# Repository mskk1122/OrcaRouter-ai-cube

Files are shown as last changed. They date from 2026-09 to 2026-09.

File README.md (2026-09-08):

# AI Cube

머리를 톡 건드리면 이야기를 듣고 대답하는 작은 책상 친구. Raspberry Pi Zero2W와 OrcaRouter를 사용한다.

**이 저장소는 코드·배선·케이스를 포함한 제작용 프로토타입 패키지다. 실제 부품 조립 및 유료 API 호출은 아직 검증하지 않았다.**

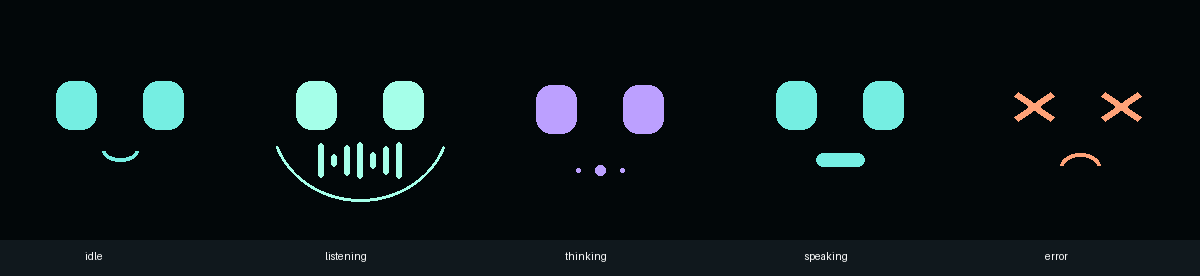
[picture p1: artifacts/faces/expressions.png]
상태별 화면


## 구성

- 약82×78×82mm 큐브, 둥근 모서리, 바깥에 센서가 드러나지 않는 머리.
- 1.3인치 컬러 화면: 대기 / 듣기 / 생각 / 말하기 / 오류 표정.
- 안쪽 정전식 전극과 AT42QT1010. 손을 대면 한 번 녹음하며 손을 떼어도 계속 듣는다.
- USB 마이크 → OrcaRouter 음성 이해·추론 → OrcaRouter TTS → MAX98357A와 스피커.
- 녹음 최대12초, 무발화5초 취소, 발화 후1초 무음 종료. 대기 중에는 마이크 입력을 열지 않는다.
- 유선5V 전원. 클라우드 추론이라 Pi에 대형 모델을 올릴 필요가 없다.

## 제작 파일

| 시작할 일 | 파일 |
|---|---|
| 부품 고르고 연결하기 | [BOM·정확한 배선](docs/hardware.md) |
| OS 설치부터 작동시키기 | [설치·점검·자동 실행](docs/setup.md) |
| 케이스 출력·조립하기 | [케이스 모델과 조립 안내](docs/enclosure.md), [CAD 폴더](cad/) |
| API 키·기기 설정 | [.env.example](.env.example) |
| 실행 코드 | [ai_cube](ai_cube/) |
| 부팅 자동 실행 | [systemd 서비스](deploy/ai-cube.service) |
| 검증 범위 확인 | [테스트 기록·실물 합격 기준](docs/verification.md) |
| 설계 기준 | [design.md](docs/design.md) |

```bash
python -m pip install Pillow numpy
python -m unittest discover -s tests -v
python -m ai_cube --simulate
```

위 명령은 PC에서 돌리는 오프라인 미리보기다. 실제 Pi 실행은 [설치 안내](docs/setup.md)를 따른다. API 키는 기기의 `.env`에만 넣는다.

## 동작

`머리 감지 → 듣는 표정 → 녹음 → 생각하는 표정 → API 답변 생성 → 말하는 표정과 음성 → 대기`

감지부는 플라스틱 안쪽의 **접촉·초근접 정전식 센서**다. 공중 감지 거리는 조립 상태에 따라 달라지므로 수cm 거리 감지를 보장하지 않는다. 음량 기반 발화 판정, 독립적인1회 질문, 상태 기반 입 애니메이션을 제공한다. 장기 기억·상시 청취·답변 도중 끼어들기는 구현 범위에 포함하지 않았다.

OrcaRouter의 [음성 입력 공식 문서](https://docs.orcarouter.ai/advanced/audio-input)와 [TTS 공식 문서](https://docs.orcarouter.ai/other-apis/tts)에 맞춘 어댑터다. 기본 음성 모델은 `google/gemini-2.5-flash`, TTS는 `openai/tts-1`. 모델 가용성·계정 권한·실제 응답은 본인의 키로 최종 확인해야 한다.

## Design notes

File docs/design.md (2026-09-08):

# AI Cube — 설계 기준 (2026-09-07)

사용자가 부품 선정·외형·구현을 위임한 새 프로젝트. 현재 작업 폴더는 파일과 커밋이 없는 초기 저장소이므로 이 폴더에 제작물을 만든다.

## 제품

- 책상용 둥근 모서리 큐브. 약 82 × 78 × 82 mm, 유선 5V 전원, 배터리 없음.
- Raspberry Pi Zero 2 W + Raspberry Pi OS Lite 64-bit, Python 3.11 이상.
- 전면 Waveshare 1.3inch LCD Module, ST7789 240×240 SPI: 검정 배경에 두 눈. 대기/듣기/추론/말하기/오류 표정.
- 머리 외부는 구멍이나 센서가 없는 불투명 비금속 플라스틱. 안쪽 35×35 mm 구리 전극, AT42QT1010 Adafruit #1374, 3.3V 동작. 접촉·초근접 감지를 목표로 하고 공중 감지 거리 보장 없음. 상판 센서 영역 1.0 mm, 그 외 2 mm. 센서 감지 후 손을 떼도 녹음 유지.
- Adafruit Mini USB Microphone #3367 + 짧은 Micro USB OTG 케이블. MAX98357A #3006 + 40 mm 4Ω 3W 스피커.
- USB 마이크는 입력, I2S는 출력 전용으로 나누어 GPIO 충돌 및 커스텀 전이중 오디오 드라이버를 피한다.

## 상태·개인정보

idle → listening → thinking → speaking → idle. 예외 시 error → idle.
대기 중 마이크 장치를 열지 않는다. 감지 후 최대 12초 녹음, 5초 무발화 취소, 발화 후 1초 무음 종료. 녹음 시작 전 스피커 알림음 사용 안 함. 듣기 중 화면으로 알린다.
한 번 감지당 한 대화만 실행. 처리 중 새 감지는 버리며, 대기 복귀 후 손을 떼고 다시 감지해야 재실행. 시작 시 손을 떼야 활성화. 키·음성·대화 본문은 로그에 쓰지 않고 오디오는 메모리/임시 디렉터리에서 처리 후 제거한다.

## API

공식 https://docs.orcarouter.ai/advanced/audio-input 과 /other-apis/tts 확인.
base URL https://api.orcarouter.ai/v1. POST /chat/completions에 WAV base64 input_audio를 보내 음성 이해+응답을 한 번에 요청. 기본 google/gemini-2.5-flash (공식 음성 입력 예시), 모델은 환경변수로 교체. 자동 라우터가 음성 지원 모델을 고른다고 가정하지 않는다.
POST /audio/speech, openai/tts-1, voice alloy, response_format wav. 동일 OrcaRouter 키 사용. 유한 timeout, HTTP 오류·잘못된 응답·오디오 오류 시 복귀. 클라이언트 자동 재시도 없음(중복 과금 방지). 실제 키가 없으므로 유료 API 성공 주장은 하지 않는다.

## GPIO 계약 (BCM)

LCD MOSI 10, SCLK 11, CS 8, DC 25, RST 27, BL 24.
AT42QT1010 OUT 17 (active high, 3.3V).
MAX98357A BCLK 18, LRC 19, DIN 21, VIN 5V, GND 공통.
스피커는 앰프 +/− 사이에만 연결한다.

## 산출물과 검증

Python 실행 코드, 오프라인 시뮬레이션, 오류·상태·무음·API 페이로드 테스트, systemd 예제, 한국어 설치/배선/BOM/제작 안내, 편집 가능한 CAD 및 STL, 실제 CAD 기반 미리보기.
실물 조립·GPIO·음성 품질·센서 거리·열·최종 끼움 공차는 미검증으로 명시한다. CAD 치수의 제조사 출처와 설계 여유/가정은 분리한다.

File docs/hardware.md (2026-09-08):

# 부품 선정과 배선

이 구성은 **Raspberry Pi Zero 2 W + USB 입력 + I2S 출력 + SPI 화면 + 디지털 정전식 센서**다. 모든 GPIO 번호는 BCM이며 물리 핀도 함께 적었다. 납땜과 조립은 전원을 분리한 상태에서 한다.

## 구매 목록

| 역할 | 선정 부품 / 수량 | 선정 이유·확인 사항 |
|---|---|---|
| 본체 | Raspberry Pi Zero 2 W ×1 | 65×30 mm, RAM512MB, 2.4GHz Wi-Fi. 연산은 API에서 수행 |
| 저장 | microSD 32GB, A1 등급 ×1 | Raspberry Pi OS Lite 64-bit. 카드·전원은 별도 |
| GPIO | 2×20 2.54mm 핀헤더 ×1 | Zero2W 기본형은 미실장. 직각/일자 선택 시 케이스 내부 높이 확인 |
| 얼굴 | Waveshare **1.3inch LCD Module, SKU15867** ×1 | ST7789, 240×240, PCB45×31mm. OLED/HAT/Pico 버전과 구분 |
| 마이크 | Adafruit **Mini USB Microphone #3367** ×1 | 약22.2×18.3×7mm. USB 오디오 입력, GPIO 미사용 |
| USB 케이블 | Micro USB 수 → USB-A 암 **OTG 데이터** 짧은 케이블 ×1 | Pi의 USB 포트에 연결. 커넥터와 꺾임 공간은 별도 필요 |
| 음성 앰프 | Adafruit **MAX98357A #3006** ×1 | I2S 입력, 모노 Class-D 출력. 5V 급전, 3.3V 신호 |
| 스피커 | Adafruit **#3968**, 40mm, 4Ω ×1 | 현재 제품명5W, 이전3W. MAX98357A 출력 범위로 구동. 약20mm 깊이 |
| 머리 센서 | Adafruit **AT42QT1010 #1374** ×1 | 순간형 active-high 출력. 토글형 AT42QT1012와 구분 |
| 숨김 전극 | 구리 테이프 35×35mm ×1 | 상판 내부에 붙이고 센서의 외부 전극 패드에 납땜 |
| 전원 | 정품급 **5.1V 2.5A Micro USB 전원** ×1 | Pi PWR IN 포트에 연결. 배터리/충전 회로는 사용하지 않음 |
| 배선 | 짧은 절연선, 수축튜브, 소형 전원 분배 기판 | 납땜 또는 고정 커넥터. 뒤틀리는 임시 점퍼는 최종 조립에서 고정 |
| 제작 부자재 | PLA/PETG, 나일론 나사·너트, 얇은 절연 테이프, 폼 가스켓, 케이블타이 | 규격·수량은 [케이스 안내](enclosure.md) 기준 |

가격은 지역·배송·보드 리비전에 따라 달라지므로 구매 시 위 **제품 번호**를 기준으로 확인한다. 실제 부품 구매는 수행하지 않았다.

## 전원과 신호

| 부품 단자 | Raspberry Pi BCM / 전원 | 물리 핀 | 비고 |
|---|---|---:|---|
| LCD VCC | 3V3 | 1 | 이 모델의 3.3V 입력 사용 |
| LCD GND | GND | 6 | 공통 접지 |
| LCD DIN | GPIO10 / MOSI | 19 | SPI0 |
| LCD CLK | GPIO11 / SCLK | 23 | SPI0 |
| LCD CS | GPIO8 / CE0 | 24 | SPI0.0, active-low |
| LCD DC | GPIO25 | 22 | 명령/데이터 |
| LCD RST | GPIO27 | 13 | active-low |
| LCD BL | **GPIO24** | **18** | 제조사 예제 GPIO18에서 변경! |
| QT1010 VIN | 3V3 | 17 | **5V로 구동하지 않는다**: OUT을 Pi에 직접 연결 |
| QT1010 GND | GND | 9 | 공통 접지 |
| QT1010 OUT | GPIO17 | 11 | 감지 시3.3V, 소프트웨어40ms 디바운스 |
| QT1010 외부 전극 패드 | 구리 전극 | — | 전원·GND가 아닌 외부 감지 패드. 짧은 절연선 |
| MAX98357A VIN | 5V | 2 | 앰프 전원은 GPIO 출력이 아닌5V 전원 핀 |
| MAX98357A GND | GND | 14 | Pi와 공통 |
| MAX98357A BCLK | GPIO18 / PCM_CLK | 12 | **LCD BL과 공유 금지** |
| MAX98357A LRC | GPIO19 / PCM_FS | 35 | I2S 워드 클록 |
| MAX98357A DIN | GPIO21 / PCM_DOUT | 40 | Pi에서 앰프로 출력 |
| MAX98357A SD/MODE | 연결 없음 | — | Adafruit 보드 기본 풀업/모노 믹스 사용. overlay의 no-sdmode와 짝 |
| MAX98357A GAIN | 연결 없음 | — | 기본 이득. 앱에서 PCM 볼륨25%로 시작 |
| 앰프 SPK+ / SPK− | 스피커 두 단자 | — | **스피커 어느 단자도 GND에 연결하지 않는다** |
| USB 마이크 | Pi **USB** → OTG → 마이크 | — | PWR IN 포트와 구분 |
| 전원 어댑터 | Pi **PWR IN** | — | 외부 전원 입력은 이 포트 하나 |

GPIO20(PCM_DIN) 및 SPI MISO는 이 설계에서 사용하지 않는다. GPIO와 전원핀은 서로 바꾸면 안 된다. 헤더 방향을 사진만 보고 추정하지 말고 보드의 1번 핀과 공식 핀맵을 확인한다.

```mermaid
flowchart LR
    PSU[5.1V / 2.5A 전원] -->|PWR IN| PI[Pi Zero 2 W]
    HEAD[상판 안쪽 구리 전극] --- CAP[AT42QT1010 · 3.3V]
    CAP -->|OUT · GPIO17| PI
    MIC[USB 마이크] -->|짧은 OTG · USB 포트| PI
    PI -->|SPI0 · BL GPIO24| LCD[ST7789 표정 화면]
    PI -->|GPIO18 / 19 / 21| AMP[MAX98357A · 5V]
    AMP -->|SPK+ / SPK−| SPK[4Ω 스피커]
    PI <-->|Wi-Fi · HTTPS| API[OrcaRouter · 음성 이해 / 추론 / TTS]
```

## 머리를 만지는 동작

센서는 상판 내부에 숨긴다. 상판 중심 감지 영역의 플라스틱 두께는1.0mm, 구리 전극은35×35mm다. **손을 가볍게 대거나 매우 가까이 가져가는 동작**을 목표로 한다. 이 부품은 거리 센서가 아니므로 수cm 떨어진 손을 안정적으로 검출한다고 보장하지 않는다. 기본 합격 기준은 케이스 외부 접촉으로 작동하는 것이며 비접촉 거리는 조립 후 기록한다.

전극은 매끈하게 밀착하고 도선은 가급적30mm 이내로 한다. 검정 도전성/탄소 섬유 필라멘트, 금속 도장, 전극 바로 아래 접지판을 피한다. 스피커 자석·앰프·클록선·전원선과 떨어뜨린다. 센서 보드의 표시 LED는 상판 밖으로 보이지 않도록 내부에서 차광한다. 플라스틱 소재, 습도, 케이블과 책상 접지 상태에 따라 감도는 달라진다.

완전히 조립한 뒤 손을 떼고 전원을 켜 자동 보정되게 한다. 짧은 접촉 후 손을 떼어 말하면 된다. 장시간 누르면 센서 자체의 보정/타임아웃 동작이 있을 수 있으므로 길게 누르는 제스처는 기능으로 쓰지 않는다. 감도가 부족하면 먼저 접착 공극·전극 연결·상판 두께를 확인한다. 감도 캐패시터 변경은 제조사 가이드와 데이터시트에 따른 실물 튜닝 단계이며, 코드 값으로 아날로그 감도를 높일 수는 없다.

## 소리·열·조립

- 마이크의 실제 음향 구멍을 케이스 마이크 그릴 쪽으로 향하게 하고 얇은 폼으로 통로를 만든다. 스피커와 마이크 사이에 폼을 넣어 기구 진동을 줄인다.
- 답변 재생 중에는 마이크 입력을 열지 않는다. 다만 말하는 중 끼어들기/에코 제거 기능은 제공하지 않는다.
- 스피커 선은 짧게 꼬아서 전극에서 떨어뜨린다. Pi 안테나 주변에는 구리 전극·금속·케이블 다발을 붙이지 않는다.
- 전원 분기에는 절연된 분배 기판을 사용하고 여러 선을 한 핀에 억지로 끼우지 않는다. 앰프 가까이100µF/10V 전해 캐패시터를 추가하는 것은 노이즈가 있을 때의 선택 부품이며 극성을 확인한다.
- 통풍구와 외부 전원 케이블을 막지 않는다. 조립 후30분 동작에서 온도와 저전압 플래그를 확인한다. 실물 발열·EMI·오디오 품질은 아직 시험하지 않았다.

## 제조사 근거 (2026-09-07 확인)

- [Raspberry Pi Zero2W 규격](https://www.raspberrypi.com/products/raspberry-pi-zero-2-w/)
- [Waveshare SKU15867 LCD](https://www.waveshare.com/product/displays/lcd-oled/lcd-oled-3/1.3inch-lcd-module.htm), [제조사 드라이버 예제](https://files.waveshare.com/upload/8/8d/LCD_Module_RPI_code.zip)
- [Mini USB microphone #3367](https://www.adafruit.com/product/3367)
- [AT42QT1010 #1374](https://www.adafruit.com/product/1374), [센서 가이드](https://learn.adafruit.com/adafruit-capacitive-touch-sensor-breakouts)
- [MAX98357A #3006](https://www.adafruit.com/product/3006), [Pi 설정 가이드](https://learn.adafruit.com/adafruit-max98357-i2s-class-d-mono-amp/raspberry-pi-usage)
- [스피커 #3968](https://www.adafruit.com/product/3968)
- [Pi Linux max98357a overlay 소스](https://github.com/raspberrypi/linux/blob/rpi-6.12.y/arch/arm/boot/dts/overlays/max98357a-overlay.dts): no-sdmode 옵션, 카드명MAX98357A 확인. 설치된 OS의 `dtoverlay -h max98357a`도 확인한다.

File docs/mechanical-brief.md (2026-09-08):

# Mechanical task — AI Cube

Own ONLY cad/ and docs/enclosure.md (plus docs/mechanical-report.md). Work in current empty project; no commits, no subagents. The parent builds code and hardware docs independently. User delegated all design choices, proceed without questions for reversible design work.

Design an attractive rounded compact desk cube roughly 82 W ×78 D ×82 H mm. You may increase slightly if engineering requires it, report decision early. Solid unmarked opaque top conceals 35×35mm copper capacitive electrode, top localized 1mm membrane, other walls ~2mm. Front Waveshare 1.3inch LCD Module ST7789 240×240, likely PCB40.5×37.5mm (verify official dimensions), active viewing roughly23.4mm square. Need correct accessible front window, retain LCD without adhesive on active display. Pi Zero2W board65×30mm holes58×23mm, M2.5 mounts; USB mic Adafruit3367 22.2×18.3×7mm excluding OTG cable/socket; QT1010 Adafruit1374 20×28mm; MAX98357A Adafruit3006 19.4×17.8mm allow 12mm height terminal/header; speaker40mm dia4ohm3W generic envelope depth20mm pending specific selection. Provide generic cable/service openings rather than pretend exact port cutouts verified. Power through Pi PWR IN; micro-USB OTG cable from Pi USB port to microphone. Plan enough cable connector+turn space (not just board boxes). Mic grille at front/side separated from speaker. Side/rear speaker grille, vents, removable screw-fastened base, reachable SD access via base acceptable. Nonmetallic fasteners/spacers or isolated mounting; top sensor board near electrode with short cable away from speaker/magnet and power lines. Top electrode not over grounded Pi.

Correction from official product search: Waveshare LCD PCB is 45.0×31.0mm, active23.4×23.4mm, PH2.0 connector. 40.5×37.5 is the OLED, not our LCD! Verify at https://www.waveshare.com/catalog/product/view/id/3637/s/1.3inch-lcd-module/category/356/ . Speaker pick Adafruit3968 (currently titled 4ohm5W, older3W), roughly square40mm driver. Verify envelope https://www.adafruit.com/product/3968 .

Deliver editable parametric CAD (OpenSCAD or reproducible Python CAD acceptable), actual binary/ASCII STL per printed part, actual mesh/CAD rendered PNG and preferably assembly/exploded preview. Need functional mounting/retention for all components including mic and amp (designed tie slots or removable brackets with tape support acceptable, document). State unverified purchased-board holes as measured-before-print parameters, do not fabricate dimensions. FDM PLA/PETG printable orientation, tolerances, screws+assembly Korean instructions. Verify STL closed/watertight, positive volume, separate print pieces, no detached islands intended as one part. Avoid unverified claim ready manufactured; label prototype CAD requiring physical dry fit. Can use bundled Python C:/Users/mskwo/.cache/codex-runtimes/codex-primary-runtime/dependencies/python/python.exe (Pillow+numpy available; no trimesh/manifold/cadquery initially). Can install CAD packages in .tools if needed without touching global Python. No openscad in PATH. Prefer real CSG via manifold3d if obtainable, else find installed CAD runtime read-only. Read official primary sources by web for dimensions. Use tools available. Final report docs/mechanical-report.md with commands, file names, key dimensions, issues. Parent will review. Keep response concise.

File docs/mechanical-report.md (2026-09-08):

# Mechanical delivery report — 2026-09-07

## Delivered

- `cad/enclosure.py`: editable parametric Python CAD with true Manifold Boolean solids; includes reproducible mesh export, geometric validation, and depth-buffer raster rendering.
- `cad/requirements.txt`, `cad/.gitignore`: pinned core CAD dependencies; locally installed `cad/vendor/` excluded from source control.
- `cad/stl/shell.stl`: 149,784-byte binary STL; print with exterior top on bed (already oriented).
- `cad/stl/base.stl`: 142,284-byte binary STL; print flat (already oriented).
- `cad/renders/assembly.png`, `exploded.png`, `cutaway.png`, `print-layout.png`: actual CAD mesh renders, 1280 × 1024 pixels; inspected visually. The cutaway and component blocks are reference illustrations, not extra printed parts.
- `cad/validation.json`: generated validation evidence.
- `docs/enclosure.md`: Korean sourcing notes, physical assembly, printing, fasteners, tolerances, routing, and limitations.

No commits, purchases, paid services, or changes outside the assigned CAD/doc ownership were made. CAD libraries required an approved network install and approved local DLL execution because the managed sandbox initially blocked them. Both succeeded; no approval blocker remains.

## Dimensions and design decisions

Kept 82 W × 78 D × 82 H mm. XY corner radius 6 mm, normal wall/top 2 mm, hidden local top membrane 1 mm over a 37 × 37 mm recess. Copper electrode is 35 × 35 mm. Unmarked top remains fully opaque and closed.

Official Waveshare primary product search and PDF confirm PCB **45 × 31 mm**, active **23.4 × 23.4 mm**, PH2.0 connector. Explicitly corrected the unrelated OLED 40.5 × 37.5 mm size. Front window is 25.4 mm square, display centre Z48 mm. LCD is retained at PCB edges by integral guides and nylon ties, without adhesive on the active display.

Adafruit3968 official page confirms 40 mm overall and 20 mm height; current title is 4 ohm 5 W, with a 2024 revision from the older 3 W design. A conservative 40 × 40 × 20 mm box fits the right-side U cradle. Frame foam and two ties behind the magnet retain it; the diaphragm is not clamped.

Pi is vertical at rear, on known 58 × 23 mm M2.5 centres, with PCB Z16–46. The grounded PCB plane lies outside the electrode footprint. USB edge faces upward, with connectors biased left. Reserved USB plug/turn corridor is 38 × 20 × 24 mm, and LCD lead corridor is 8 × 12 × 16 mm. Sensor is upper-left, mic lower-front-left, amp lower centre. Every component has a physical retention feature. Unknown board mounting-hole patterns are deliberately unused.

Base closes with four M3 nylon screws and captive nylon nuts. SD access requires base removal. Rear 20 × 9 mm opening is a generic service/cable opening with separate tie-down strain relief, not a falsely precise port cutout. Power goes to Pi PWR IN; microphone goes through a flexible OTG cable to Pi USB.

## Reproduction and actual checks

```powershell
& 'C:/Users/mskwo/.cache/codex-runtimes/codex-primary-runtime/dependencies/python/python.exe' -m pip install --target cad/vendor manifold3d trimesh
& 'C:/Users/mskwo/.cache/codex-runtimes/codex-primary-runtime/dependencies/python/python.exe' cad/enclosure.py
```

Final CAD command exited 0. It exports STL, reloads the files in trimesh, validates watertightness and winding, checks positive volume, and counts connected vertex components. It also evaluates actual Boolean intersections in assembly coordinates.

| Check | Shell | Base |
|---|---:|---:|
| Watertight | true | true |
| Consistent winding | true | true |
| Connected bodies | 1 | 1 |
| Volume mm³ | 66,473.29 | 26,121.65 |
| Triangles | 2,994 | 2,844 |
| Print bounds mm | 82 × 78 × 78.8 | 82 × 78 × 49 |

Shell/base intersection is numerical zero (5.33e−15 mm³). All seven reference component envelopes have zero intersection with printed material and one another. Both reserved cable corridors have zero intersection with printed material and reference component envelopes. These checks concern envelopes, not full supplier CAD models or routed cable simulations.

Visual verification opened all four PNGs. An initial painter-order preview artifact was corrected by implementing per-pixel depth buffering; final exterior correctly shows the unmarked solid top, LCD aperture, mic grille, side speaker grille, and removable base. No floating CAD islands were accepted.

## Remaining physical checks

This is prototype CAD requiring dry fit, not a manufacturing-qualified enclosure. Confirm display glass thickness and active-area centring, PCB-edge areas safe to clamp, PH2.0 direction, USB plug dimensions/turn radius, speaker revision/frame profile, foam thickness, and tie paths using purchased parts. Pi model is a board envelope rather than every mounted component. Confirm available clearance for headers and the actual microphone USB connection. Support generation, slicer review, fit coupons, tapping/reaming pilot holes, heat/acoustic/RF testing, and capacitive sensitivity calibration remain physical production steps. Internal ledges and the base frame require removable print supports.

Sources: [Waveshare LCD manual](https://files.waveshare.com/upload/7/70/1.3inch_LCD_Module_user_manual_en.pdf), [Waveshare product](https://www.waveshare.com/catalog/product/view/id/3637/s/1.3inch-lcd-module/category/356/), [Adafruit3968](https://www.adafruit.com/product/3968). The Waveshare direct open returned 403, but its official indexed product result and official PDF independently agreed on dimensions.

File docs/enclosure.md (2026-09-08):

# AI Cube 기구물 조립 안내

이 설계는 **실물 가조립이 필요한 FDM 시제품**이다. 외형은 82 × 78 × 82 mm, 모서리 평면 반경 6 mm, 일반 벽 두께 2 mm다. 상판은 불투명하고 표시·구멍 없이 막혀 있다. 안쪽의 37 × 37 mm 영역만 1 mm 두께로 줄여 35 × 35 mm 구리 전극을 숨긴다. 외피와 받침 사이의 설계 간격은 0.2 mm다.

## 파일과 재생성

- `cad/enclosure.py`: 편집 가능한 Python/Manifold CSG 원본. mm 단위이며 X 오른쪽, Y 뒤쪽, Z 위쪽이다.
- `cad/stl/shell.stl`, `cad/stl/base.stl`: 실제 이진 STL, 각각 **1개씩** 출력한다. 각 파일은 단일 연결 폐곡면이다.
- `cad/renders/assembly.png`: 실제 CAD 외관, `exploded.png`: 분해 참고도, `cutaway.png`: 전면 절개 부품 배치, `print-layout.png`: 출력 방향.
- `cad/validation.json`: STL 재로딩 검사와 부품·케이블 공간 간섭 검사 결과.

Python 3.12 환경에서 다음 명령으로 재생성한다. 설치는 프로젝트 로컬 폴더에만 한다.

```powershell
python -m pip install --target cad/vendor -r cad/requirements.txt
python cad/enclosure.py
```

주요 치수는 원본 상단에서 변경한다. 치수를 변경하면 고정 좌표로 정의한 배치도 함께 검토하고 검사를 다시 실행한다. `LCD_X`, `LCD_Z`는 실물 PCB 중심과 표시 영역 중심의 오프셋을 반영하는 값이다. `M25_PILOT`, `M3_CLEAR`, `M3_NUT_AF`는 프린터 보정용이다. 미확인 보드 장착 구멍은 사용하지 않았다. 좌우 뒤집힌 LCD나 Pi 방향은 소프트웨어 화면 회전 및 케이블 방향까지 확인한다.

## 부품과 공간

| 부품 | 설계 기준 / 배치 | 고정 방법 |
|---|---|---|
| Waveshare 1.3inch LCD Module | PCB 45 × 31 mm, 표시 23.4 mm 정사각형, 전면 창 25.4 mm, 중심 높이 48 mm | 전면 가장자리 받침과 양옆 가이드; 타이 2개를 슬롯에 통과시켜 **PCB 비활성 가장자리**만 눌러 고정 |
| Pi Zero 2 W | 65 × 30 mm, 홀 간격 58 × 23 mm, 뒤쪽 수직 배치; PCB 높이 Z16–46 | 받침 일체형 프레임 + 4개 M2.5 절연 나사, 스탠드오프 |
| Adafruit 3968 스피커 | 보수적인 40 × 40 × 20 mm 상자, 오른쪽 측면 | 40.8 mm 폭 U 받침, 얇은 폼 가스켓, 뒤쪽 슬롯에 타이 2개; 콘·진동판·단자에 힘을 가하지 않음 |
| USB 마이크 Adafruit 3367 | 22.2 × 18.3 × 7 mm, 아래 앞쪽 왼편 | 바닥 트레이 + 얇은 절연 패드 + 바닥 슬롯 타이; 수음 구멍을 가리지 않음 |
| MAX98357A Adafruit 3006 | 19.4 × 17.8 mm, 터미널 포함 12 mm 높이 공간 | 중앙 바닥 트레이 + 절연 패드 + 슬롯 타이 |
| QT1010 Adafruit 1374 | 20 × 28 mm, 위쪽 왼편 수직 배치 | 측벽 U 받침 + 절연 패드 + 슬롯 타이 |
| 구리 전극 | 35 × 35 mm, 상판 내부 앞쪽; X±17.5, Y−20.5…14.5 | 얇은 접착 구리박, 가장자리 절연; 센서와 짧게 연결 |

LCD 치수는 [Waveshare 공식 매뉴얼](https://files.waveshare.com/upload/7/70/1.3inch_LCD_Module_user_manual_en.pdf)과 [공식 제품 정보](https://www.waveshare.com/catalog/product/view/id/3637/s/1.3inch-lcd-module/category/356/)의 45 × 31 mm를 사용했다. 40.5 × 37.5 mm는 다른 OLED 제품 치수이므로 사용하지 않는다. 스피커는 [Adafruit 3968 공식 제품 정보](https://www.adafruit.com/product/3968)의 40 mm, 높이 20 mm를 적용했다. 현재 제품은 5 W로 표기되며 2024년 개정 이력이 있다. 나머지 보드 치수는 프로젝트 요구사항의 외곽 기준이며 수령품에서 확인한다.

Pi의 USB 단자 변이 위쪽이고 USB 단자들이 왼쪽에 오도록 놓는다. 상부 뒤쪽에 **38 × 20 × 24 mm** 커넥터·케이블 꺾임 공간(X−30…8, Y3…23, Z46…70)을 확보했다. 작은 유연한 OTG 연장선을 사용하고 단단한 USB 변환 젠더를 직접 꽂지 않는다. LCD PH2.0 리드는 왼쪽 여유 공간 **8 × 12 × 16 mm**로 배선한다. 커넥터의 실제 돌출, PH2.0 방향, USB 플러그 길이와 굽힘 반경은 반드시 실물 확인하며 이 공간 검사는 해당 케이블 호환성 인증이 아니다.

전원선은 후면 **20 × 9 mm 일반 서비스 개구부**로 넣어 Pi의 **PWR IN**에 연결한다. USB 마이크는 Pi의 **USB** 데이터 단자에 OTG 케이블로 연결한다. 후면 구멍에 모서리 보호용 그로밋을 끼우고 바닥 타이 슬롯으로 별도 장력 완화를 한다. 정확한 포트 일치 절개는 없다. SD 카드는 받침 나사 4개를 풀고 받침을 내려 접근한다. 마이크 선은 왼쪽, 스피커 전력선은 오른쪽으로 배선하고 센서 리드는 상판 왼쪽에 짧게 유지한다. Pi의 접지면은 Y22.4 이상으로, 전극 투영 영역과 겹치지 않는다.

## 출력 및 체결

PLA 또는 PETG, 0.4 mm 노즐, 0.2 mm 레이어, 벽 3줄 이상을 시작점으로 사용한다. 외피 STL은 이미 **상판이 출력 바닥에 닿도록 뒤집혀** 있다. 받침 STL은 바닥이 Z0에 놓여 있다. 상판 1 mm 막이 5개 레이어로 연속 출력되는지 슬라이서에서 확인한다. 윗면이 노출되는 디자인이므로 매끈한 빌드 플레이트를 권장한다.

내부 선반·너트 보스, LCD 창 상단, Pi 프레임 가로대와 수평 스탠드오프에는 **서포트가 필요하다**. 자동 서포트를 그대로 신뢰하지 말고 단면 미리보기에서 돌출 시작점을 확인한다. 트리/유기 서포트와 인터페이스를 사용하되 타이 구멍, 나사 구멍, 1 mm 막 안쪽은 과도한 접착을 피한다. 서포트 제거 후 모든 슬롯을 청소하고 가조립한다. 0.4 mm 좌우 여유 및 나사 구멍 공차는 프린터에 맞춰 조정한다. 상판 막을 사포로 더 얇게 만들지 않는다.

준비물: M3 나일론 나사 4개(약 12–14 mm, 실물 적층 높이로 최종 선택), M3 나일론 너트 4개, M2.5 나일론 나사 4개(약 6 mm), 절연 와셔, 폭 1.5 mm 이하 소형 나일론 타이 약 10개, 얇은 절연 패드, 스피커 프레임용 얇은 폼, 그로밋. 금속 체결재를 쓰면 보드 및 전극과 절연한다. 전극 주변에는 금속 체결재를 배치하지 않는다.

1. 수령한 보드·디스플레이·스피커와 USB/PH2 케이블의 실제 외곽과 돌출을 측정한다. LCD 표시 영역 중심, glass/PCB 두께와 커넥터 방향을 확인하고 필요하면 원본 매개변수와 가이드를 수정한다.
2. 출력물 서포트와 버를 제거한다. M2.5 파일럿은 적절한 탭으로 가공하거나 실물 나사에 맞게 조정한다. 억지로 조여 프레임을 쪼개지 않는다. 외피 보스 위쪽 육각 포켓에 M3 너트를 넣고 소량의 절연 테이프로 빠짐을 방지한다.
3. 외피 안쪽 상판에 전극을 붙이고 QT1010을 측벽 받침에 고정한다. 전극 배선을 짧게 연결하되 스피커 자석과 전원선에서 떨어뜨린다.
4. LCD를 전면 받침에 놓는다. 활성 유리면에는 접착제나 타이를 대지 않는다. 가이드 슬롯에 타이를 걸어 PCB 양끝의 안전한 가장자리만 지지한다. 부품이 그 자리를 차지하면 얇은 절연 스페이서를 추가하거나 가이드를 수정한다.
5. 스피커의 단단한 프레임에만 폼을 대고 U 받침에 넣는다. 측벽 슬롯을 연결하는 타이를 자석 뒤로 지나가게 해 프레임을 눌러 고정한다. 전기 단자와 진동판에는 닿지 않게 한다.
6. Pi를 받침 수직 프레임에 절연 나사로 체결하고, 마이크·앰프를 패드와 타이로 트레이에 고정한다. 마이크 수음부에서 전면 그릴까지 짧은 비밀폐 공기 경로를 확보한다. 필요하면 얇은 폼으로 안내하되 수음부를 막지 않는다.
7. 케이블을 연결하고 외피를 조심스럽게 씌워 선이 눌리지 않는지 확인한다. 아래에서 M3 나사 4개를 체결한다. 마지막 조임 전에 센서, 화면 정렬, 마이크 녹음, 스피커 재생, 전원 케이블 장력 완화를 확인한다.

최종 접촉 압력·낙하 강도·공진·마이크 피드백·RF·열 성능은 아직 실험하지 않았다. 통풍구는 후면에 있으나 연속 부하 온도 시험을 거쳐야 한다. 스피커와 마이크가 같은 작은 공간을 공유하므로 소프트웨어 재생/수음 정책과 실제 음향 시험도 필요하다.

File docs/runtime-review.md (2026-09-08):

# Runtime review — 2026-09-07

## Resolution — 2026-09-08

Both P2 findings below are resolved. Production requests run in a cancellable subprocess with a total timeout and bounded output; the slow loopback response regression passes. Display state transitions synchronously transfer a frame under an SPI lock before returning; failed listening transfer prevents capture. Error-screen/idle failures no longer replace the original interaction error. All 27 tests and the offline simulation pass. The findings below are retained as review history, not open defects.

Scope: `ai_cube/*.py`, `tests/*.py`, `pyproject.toml`, `.env.example`, `THIRD_PARTY.md`, against `docs/design.md`. This is a review of newly created files, not an existing commit diff. No runtime code was changed by this review.

## Actionable findings

### P2 — Enforce an elapsed deadline for API responses

Location: `ai_cube/provider.py:57-58`.

`self.open(..., timeout=self.timeout)` followed by one `response.read(limit + 1)` does not enforce a total request deadline. urllib documents the timeout as applying to blocking operations. A server or proxy that delivers occasional bytes inside each socket timeout can keep the cube in `thinking` far beyond `CUBE_API_TIMEOUT`; the large TTS size limit makes this particularly pronounced. The UI loop is blocked during the request and cannot accept a fresh interaction until it finishes.

Use a monotonic request deadline and bounded reads with each blocking wait constrained by the remaining time, or an isolated request worker with bounded cancellation and cleanup. Keep automatic retries disabled. Add a local slow-response test that sends bytes often enough to avoid the socket inactivity timeout but exceeds the total request budget. A plain fake response that returns immediately does not exercise this failure mode.

Reference: [Python urllib.request timeout documentation](https://docs.python.org/3/library/urllib.request.html#urllib.request.urlopen).

### P2 — Confirm the listening frame before opening the microphone

Location: `ai_cube/display.py:93-95`, used by `ai_cube/core.py` in `run_turn` immediately before `audio.record()`.

`show('listening')` checks the previous animation error and merely assigns `self.state`; the actual frame is sent by the background thread at its next update. Recording therefore begins while the LCD can still show idle. If that next SPI update fails, the microphone continues recording for the turn while the LCD remains idle, because the error is only checked after `record()` returns. The screen is the only recording indicator in the design.

Make state transitions acknowledge a successfully written frame before returning, with serialization of SPI operations. Abort before `arecord` is started if the listening frame cannot be written. Add a mocked display/SPI failure test verifying that a failed first listening frame prevents microphone capture. Consider checking display health during capture if a later animation failure must also stop recording.

## Confirmed by source inspection

- No microphone process is created at startup or idle; `arecord` is opened only in `record()` after a trigger.
- Release-to-arm behavior prevents a held touch at boot or the end of a turn from immediately triggering another turn; busy inputs are discarded by resetting the latch.
- Endpointer budgets are 12 seconds of PCM, 5 seconds without detected speech, and 1 second of trailing silence. A separate wall-clock watchdog bounds stalled capture to the configured duration plus 3 seconds, followed by process shutdown time.
- Capture and playback use `finally` cleanup; speaker WAV data is removed by a temporary-directory context on ordinary success, errors, or interruption. Abrupt power loss is outside this guarantee.
- HTTP bodies have explicit byte limits, redirects are disabled, response text is bounded, and audio format/duration/frame count are validated. Credentials and response contents are not written to application logs.
- The chat payload uses WAV base64 `input_audio`; TTS requests WAV from `/audio/speech`. These agree with the [official audio input example](https://docs.orcarouter.ai/advanced/audio-input) and [TTS documentation](https://docs.orcarouter.ai/other-apis/tts) inspected during this review.
- GPIO assignments in the runtime match the design contract, including backlight GPIO24 to avoid the I2S BCLK on GPIO18. Rendering uses small 240×240 buffers and NumPy conversion rather than a Python per-pixel loop.

## Verification limits

The parent agent reported 23 unit tests passing and `python -m ai_cube --simulate` passing. Those results are supplied evidence, not independently rerun in this review: `python` was not available on this review shell's PATH. Existing tests cover pure logic and payload construction, but not ALSA subprocess cleanup, LCD update synchronization, slow HTTP bodies, or physical hardware.

There is no real Pi, connected display/sensor/audio hardware, or API key available here. ST7789 orientation/offsets and actual SPI behavior, GPIO permissions, ALSA card names, MAX98357A channel behavior, sensor calibration, acoustic endpoint thresholds, and Zero 2 W CPU/thermal measurements remain hardware acceptance work. No real API success or physical integration success is claimed.

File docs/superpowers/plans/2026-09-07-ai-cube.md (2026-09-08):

# AI Cube Implementation Plan

> For agentic workers: use superpowers:subagent-driven-development for the independent mechanical task; keep runtime integration in the parent task. The user delegated design and implementation. No publication or purchase is requested.

**Goal:** Build a reviewable Pi Zero 2 W voice companion prototype package.
**Architecture:** GPIO trigger, bounded ALSA recording, OrcaRouter audio chat + TTS, SPI animated face. Independent parametric enclosure.
**Tech Stack:** Python 3.11+, standard-library unittest/urllib, Pillow, gpiozero, spidev, ALSA; parametric CAD.
**Spec:** ../../design.md

## Global Constraints

- Raspberry Pi Zero 2 W; Korean spoken responses; OrcaRouter for both inference and speech.
- No recording in idle. One interaction per fresh sensor activation. Busy touches never queue.
- GPIO mapping exactly as docs/design.md. No API keys or real audio included in source.
- Enclosure has a solid hidden capacitive top. Mesh validity does not imply physical fit verification.

## Task 1 — mechanical package

Files: cad/*, docs/enclosure.md. Detailed requirements: ../../mechanical-brief.md.
- [ ] Check component envelopes and manufacturers' dimensions.
- [ ] Model housing, removable base, mounts and access/ventilation openings.
- [ ] Export STL and rendered preview from the actual model; inspect solids and mounting fit numerically.
- [ ] Write assembly/printing instructions and measured-vs-assumed dimensions.

## Task 2 — runtime

Files: ai_cube/*.py, tests/*.py, pyproject.toml, .env.example.
- [ ] Write failing tests for silence termination, debounced release/retrigger behavior, API payload/invalid response and state transitions.
- [ ] Implement bounded PCM recording, provider client, expression renderer, hardware adapters, state loop.
- [ ] Run `python -m unittest discover -s tests -v`; run simulation with no hardware/key.

## Task 3 — integration and handoff

Files: README.md, docs/hardware.md, docs/setup.md, deploy/*, docs/verification.md.
- [ ] Document BOM, exact BCM+physical pins, power/OTG/speaker wiring.
- [ ] Provide explicit Raspberry Pi setup, audio device selection, sensor/display bring-up and service template.
- [ ] Review runtime/CAD together, correct defects, rerun affected checks.
- [ ] Deliver local file links with clear verified/unverified boundaries.

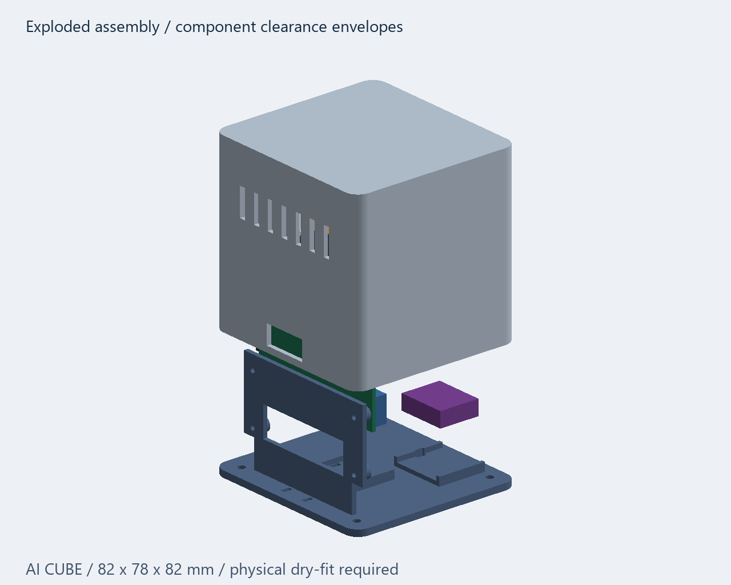
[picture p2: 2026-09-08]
cad/renders/exploded.png

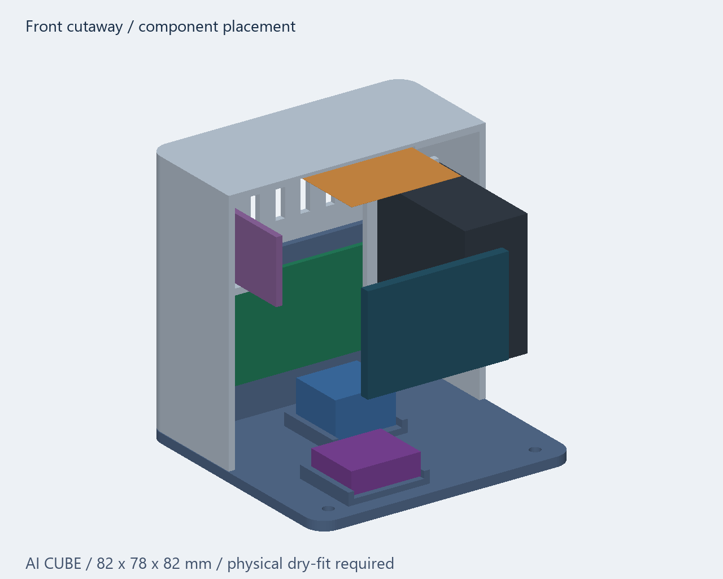
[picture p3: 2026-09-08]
cad/renders/cutaway.png

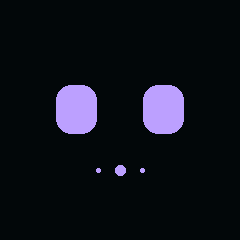
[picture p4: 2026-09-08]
artifacts/faces/thinking.png

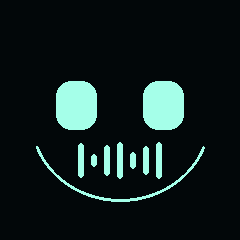
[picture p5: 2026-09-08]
artifacts/faces/listening.png

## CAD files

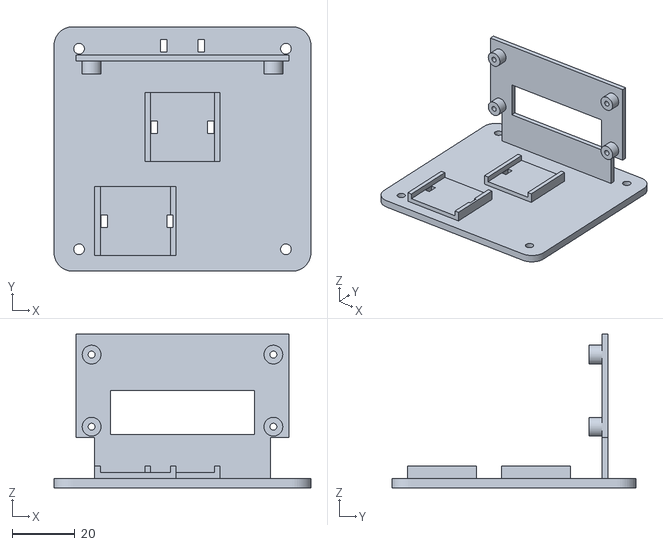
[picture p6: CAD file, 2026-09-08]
cad/stl/base.stl
82.0 x 78.0 x 49.0

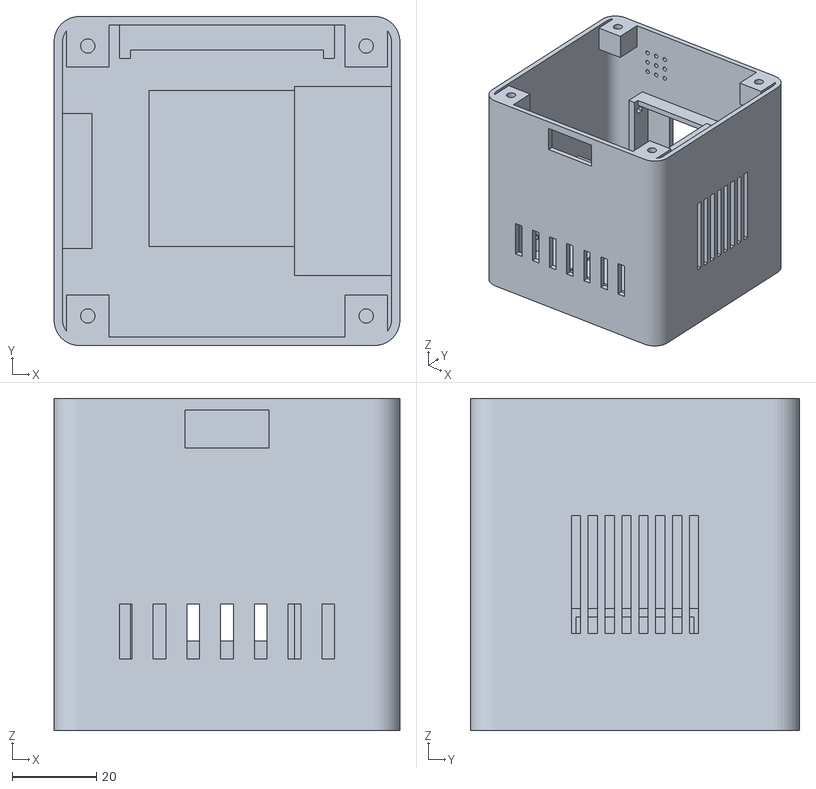
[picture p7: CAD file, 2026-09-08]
cad/stl/shell.stl
82.0 x 78.0 x 78.8

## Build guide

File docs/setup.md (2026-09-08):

# 라즈베리파이 설치·동작 점검

실물 없는 PC에서 검증된 부분과 Pi에서 직접 확인해야 하는 부분을 구분한다. 아래 명령은 **라즈베리파이의 터미널**에서 실행한다. PC 시뮬레이션은 맨 아래에 있다.

## 1. OS와 파일

Raspberry Pi Imager로 Zero2W에 Raspberry Pi OS Lite **64-bit**를 설치한다. Python3.11 이상이 있는 배포판을 사용한다. Imager에서 사용자 이름,2.4GHz Wi-Fi, SSH를 설정한다. 이 안내는 최신 부트 경로 `/boot/firmware/config.txt` 기준이다.

프로젝트 전체를 Pi의 `~/ai-cube`에 복사한다. `.tools`, `.git`, `__pycache__`는 복사할 필요가 없다.

```bash
sudo apt update
sudo apt install -y python3-venv python3-pip python3-setuptools python3-pil python3-numpy python3-gpiozero python3-lgpio python3-spidev alsa-utils rsync
cd ~/ai-cube
python3 -m venv --system-site-packages .venv
.venv/bin/python -m unittest discover -s tests -v
```

실행은 프로젝트 폴더에서 `python -m ai_cube`로 하므로 pip 패키지 설치는 필수가 아니다. 다른 경로에서 `ai-cube` 명령을 사용하려면 `.venv/bin/pip install --no-deps --no-build-isolation -e .`로 설치할 수 있다.

## 2. SPI와 스피커 overlay

먼저 [배선표](hardware.md)에 따라 연결한다. `/boot/firmware/config.txt`를 편집하고 기존 설정과 중복되지 않도록 `[all]` 아래에 다음을 넣는다. 기존 `dtparam=audio=on`은 주석 처리한다.

```ini
[all]
dtparam=spi=on
dtparam=audio=off
dtoverlay=max98357a,no-sdmode
```

`no-sdmode`는 이 프로젝트처럼 앰프의 SD 핀을 배선하지 않을 때 사용한다. 공식 Adafruit #3006의 기본 풀업을 전제로 한다. 다른 제조사의 MAX98357 보드는 SD 회로가 다를 수 있다.

```bash
dtoverlay -h max98357a
sudo usermod -aG audio,gpio,spi "$USER"
sudo reboot
```

재접속 후 확인한다.

```bash
ls /dev/spidev0.0
arecord -l
aplay -l
```

목록에 USB 마이크와 MAX98357A가 각각 있어야 한다. 카드 순번0/1은 부팅마다 달라질 수 있어 이름을 사용한다. 예를 들어 `card 1: Device [...]`라면 입력은 `plughw:CARD=Device,DEV=0`, `card 0: MAX98357A [...]`라면 출력은 `plughw:CARD=MAX98357A,DEV=0`이다. 실제 이름이 다르면 그대로 바꾼다. **예시 이름은 모든 USB 마이크에서 같지 않다.**

## 3. 설정

```bash
cd ~/ai-cube
cp .env.example .env
chmod 600 .env
nano .env
```

OrcaRouter 콘솔에서 발급받은 키를 `ORCAROUTER_API_KEY=`에 입력한다. 키는 채팅에 보내지 말고 기기에만 저장한다. 부품 테스트 전에는 비워두어도 된다.

| 값 | 기본값 | 의미 |
|---|---|---|
| ORCAROUTER_MODEL | google/gemini-2.5-flash | 공식 음성 입력 예시의 모델. 계정에서 사용 가능한 음성 지원 모델인지 확인 |
| ORCAROUTER_TTS_MODEL | openai/tts-1 | OrcaRouter의 `/audio/speech`로 호출 |
| ORCAROUTER_VOICE | alloy | TTS 목소리 |
| CUBE_CAPTURE_DEVICE | plughw:CARD=Device,DEV=0 | `arecord -l` 결과에 맞게 수정 |
| CUBE_PLAYBACK_DEVICE | plughw:CARD=MAX98357A,DEV=0 | `aplay -l` 결과에 맞게 수정 |
| CUBE_VOLUME | 0.25 | 0~1, PCM 볼륨 배율. 처음에는 낮게 유지 |
| CUBE_RMS_THRESHOLD | 550 | 1~20000, 음성 시작 판정의 PCM 에너지 기준. 정전식 감도와 무관 |
| CUBE_MAX_RECORD_SECONDS | 12 | 1~12초 녹음 상한 |
| CUBE_API_TIMEOUT | 45 | 각 API 요청의 전체 제한시간, 1~120초. 초과 시 요청 프로세스 종료 |
| CUBE_ROTATION | 0 | LCD 회전0/90/180/270 |

`.env`의 기존 운영체제 환경변수가 우선한다. 값은 단순 `KEY=VALUE` 형태이며 셸 명령·변수 치환은 실행하지 않는다.

## 4. 부품별 확인 — API 호출 없음

```bash
.venv/bin/python -m ai_cube --doctor
.venv/bin/python -m ai_cube --display-test
.venv/bin/python -m ai_cube --sensor-test
```

센서 테스트는 `detected` / `released`만 표시하고 녹음하지 않는다. 종료는 Ctrl+C. 화면 테스트는 대기/듣기/생각/말하기/오류를 차례로 표시한 뒤 꺼진다. 센서를 건드린 상태로 부팅하면 앱은 손을 떼기 전까지 대화를 시작하지 않는다.

아래 녹음 검사는 **명시적으로3초간 녹음**하므로 직접 말하며 실행한다. 장치명은 본인 기기에 맞게 바꾼다.

```bash
arecord -D plughw:CARD=Device,DEV=0 -f S16_LE -r 16000 -c 1 -d 3 /tmp/cube-mic-test.wav
```

앱과 같은25% 볼륨 변환·스테레오 변환을 적용해 스피커로 확인한다.

```bash
.venv/bin/python -c "from pathlib import Path; from ai_cube.__main__ import load_env; from ai_cube.config import Settings; from ai_cube.audio import AlsaAudio; load_env('.env'); AlsaAudio(Settings.from_env()).play(Path('/tmp/cube-mic-test.wav').read_bytes())"
rm /tmp/cube-mic-test.wav
```

화면 색상·방향·그림 잘림이 있으면 회전 설정과 **정확한 SKU15867** 여부를 먼저 확인한다. 다른 ST7789 모듈은 좌표 오프셋/초기화가 다를 수 있다.

## 5. 전체 동작

```bash
.venv/bin/python -m ai_cube
```

1. 머리에서 손을 떼고 기다린다. 대기 중에는 마이크 장치가 열리지 않는다.
2. 머리를 가볍게 건드린다. 민트색 듣기 표정이 되면 손을 떼고 말한다.
3. 약0.12초 이상 연속 소리가 나면 발화로 인식한다. 이후1초 무음이면 종료한다.5초 동안 말을 안 하면 취소하고, 계속 말해도12초에 종료한다.
4. 보라색 생각 표정에서 음성 이해·추론·TTS를 요청한다. 답변이 준비되면 입이 움직이며 재생한다.
5. 다시 머리에서 손을 뗀 상태를 거쳐야 다음 질문을 받는다. 처리 중의 접촉은 예약되지 않는다.

이 프로젝트의 무음 종료는 **간단한 음량 기반 판정**이다. 음악·팬 소음·긴 타격음도 발화로 오인할 수 있다. 조용한 환경에서 말소리가 잘리는 경우 기준을 조금 낮추고, 주변 소음으로 녹음이 끝나지 않으면 높인다. 화면의 듣기 막대와 말하기 입은 상태 애니메이션이며 실제 파형/입모양 동기화가 아니다.

현재 대화는 질문마다 독립적이다. 장기 기억과 이전 대화 전송은 없다. 녹음은 메모리에서 WAV로 만들어 OrcaRouter에 전송한다. TTS 음성은 재생용 임시 파일에만 두고 작업 종료 시 삭제한다. 강제 전원 차단까지 삭제를 보장하지는 않는다. 일반 로그에는 키·녹음·사용자 발언·답변 본문을 남기지 않는다. 인터넷 연결 및 OrcaRouter의 해당 모델 이용 권한·잔액이 필요하다.

## 6. 부팅 자동 실행 (부품 테스트 후)

서비스는 전용 계정과 `/opt/ai-cube`, `/etc/ai-cube.env`를 사용한다. 아래 계정 생성은 최초1회 실행한다. 이미 같은 이름의 계정이 있으면 재사용 여부를 먼저 확인한다.

```bash
sudo useradd --system --home-dir /opt/ai-cube --no-create-home --groups audio,gpio,spi ai-cube
sudo mkdir -p /opt/ai-cube
sudo rsync -a --exclude=.git --exclude=.env --exclude=.venv --exclude=.tools --exclude=__pycache__ ./ /opt/ai-cube/
sudo python3 -m venv --system-site-packages /opt/ai-cube/.venv
sudo install -m 600 -o ai-cube -g ai-cube .env /etc/ai-cube.env
sudo install -m 644 deploy/ai-cube.service /etc/systemd/system/ai-cube.service
sudo systemctl daemon-reload
sudo systemctl enable --now ai-cube
sudo systemctl status ai-cube
```

수동 실행 중인 앱은 Ctrl+C로 종료한 다음 서비스를 켠다. 두 프로세스가 GPIO와 오디오를 동시에 점유하면 안 된다.

```bash
journalctl -u ai-cube -n 50 --no-pager
sudo systemctl restart ai-cube
sudo systemctl stop ai-cube
```

서비스의 개인 임시 폴더는 tmpfs를 사용한다. 재부팅 시 임시 음성은 사라진다. 재생 중 전원을 바로 뽑지 말고 `sudo poweroff`로 종료한다.

## 문제 진단

| 증상 | 먼저 확인할 것 |
|---|---|
| LCD가 안 켜짐 | 3V3/GND, BL은GPIO24, SPI 활성화, gpio/spi 그룹, 단자 순서 |
| 감지 안 됨 | 센서VIN3.3V, OUT GPIO17, 외부 전극 패드 연결, 상판 공극·두께, 케이스 닫은 뒤 재보정 |
| 계속 감지됨 | 손을 떼고 재부팅, 전극과 접지/전원선 거리, 도전성 소재 여부 |
| 마이크 실패 | USB 포트와OTG 데이터 케이블, `arecord -l`, 카드 이름, 다른 녹음 프로그램 점유 |
| 소리가 안 남 | overlay 및재부팅, 앰프VIN5V, BCLK18/LRC19/DIN21, SPK 두 단자, 카드 이름 |
| 듣고 나서 오류 | 기기 시각/NTP, Wi-Fi, OrcaRouter 키·잔액·음성 모델 사용 권한, TTS 모델 |
| 소음이 질문으로 전송됨 | RMS 기준을 높이고 마이크 위치 조정. 현재 음량 게이트의 한계 |
| 재부팅/딱딱거림 | 전원 전압강하, 케이블, 볼륨, 앰프 전원 배선. 클록 시작/종료 팝은 실물에서 평가 |

```bash
vcgencmd measure_temp
vcgencmd get_throttled
```

조립 후30분 동작,50회 터치, 무발화10회, Wi-Fi 단절 후 복구를 시험한다. 자세한 합격 기준은 [검증 기록](verification.md)을 따른다.

## PC 오프라인 시뮬레이션

Python3.11 이상과 Pillow/numpy가 필요하다. Pi용 패키지는 설치하지 않아도 된다.

```bash
python -m pip install Pillow numpy
python -m unittest discover -s tests -v
python -m ai_cube --simulate
```

`artifacts/faces/`에 PNG/GIF를 만들고 상태 전이를 출력한다. 실제 API·녹음·스피커·GPIO를 사용하지 않는 시뮬레이션이다.

## API 근거

[OrcaRouter 음성 입력](https://docs.orcarouter.ai/advanced/audio-input)의 OpenAI형 `input_audio` 경로와 [TTS](https://docs.orcarouter.ai/other-apis/tts)의 `/audio/speech`를 사용한다. 음성 모델 선택을 보장할 수 없는 `orcarouter/auto`를 기본 입력 모델로 사용하지 않는다. 한 질문에 음성 포함 Chat 요청1회와 TTS 요청1회를 보내며, 클라이언트 자동 재시도는 하지 않는다. 서버의 과금 정책과 모델 목록은 콘솔에서 확인한다.

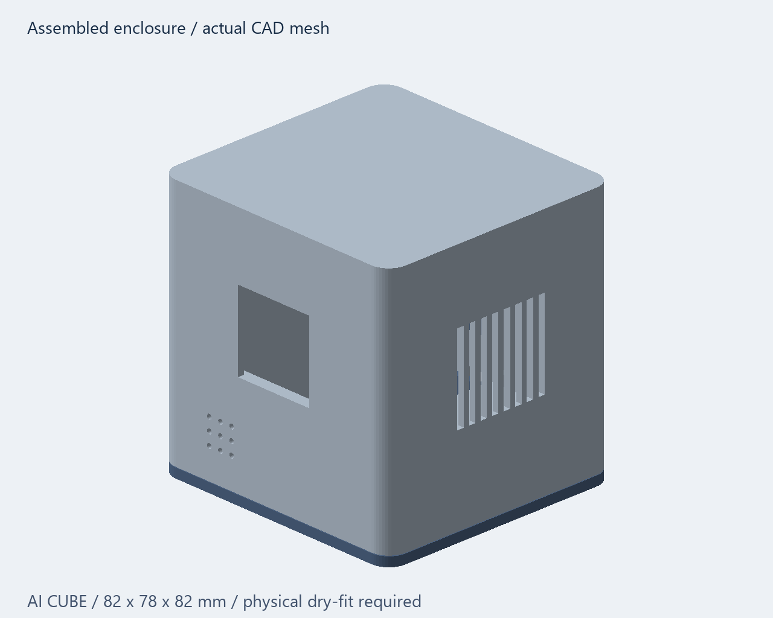
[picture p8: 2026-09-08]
cad/renders/assembly.png

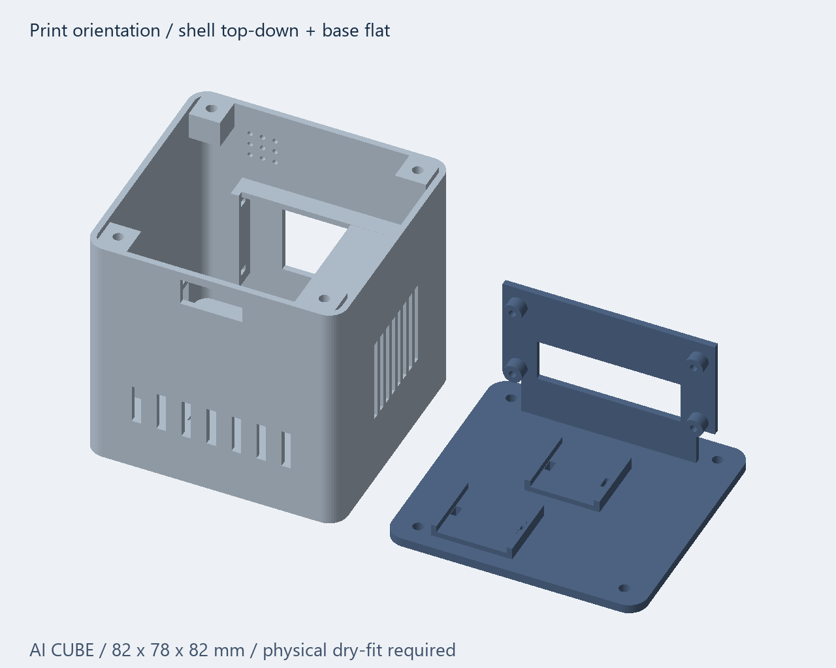
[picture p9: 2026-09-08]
cad/renders/print-layout.png

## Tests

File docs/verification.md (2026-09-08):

# 최종 검증 기록 — 2026-09-08

## 확인한 결과

- `python -m unittest discover -s tests -v`: **27개 통과**. 무발화 취소, 최대 녹음 길이, 접촉 디바운스/재활성화, 상태 전이, API 페이로드, WAV 검사·볼륨·스테레오 변환, 표정·RGB565 변환을 확인했다.
- API가 0.1초마다 데이터를 보내는 실제 로컬 HTTP 테스트에서, 1초 요청 제한을 넘기면 작업 프로세스를 종료하고 timeout 오류로 돌아오는 것을 확인했다. 실제 OrcaRouter 유료 호출은 하지 않았다.
- 듣기 프레임 전송이 녹음보다 먼저 실행되고, 첫 화면 전송 실패 시 녹음을 시작하지 않는 회귀 테스트가 통과했다. 오류 화면이 실패해도 원래 API/녹음 오류가 보존된다.
- `python -m ai_cube --simulate`: 완료. 네트워크·오디오·GPIO 없이 상태를 실행하고 `artifacts/faces/` PNG/GIF를 생성한다.
- `python cad/enclosure.py`: 실제 STL 생성/재로딩 검증. 상세 수치는 `cad/validation.json`에 있다. shell/base 모두 단일 연결 폐곡면, 올바른 면 방향, 양의 체적이다. 설계에 정의한 부품 외곽과 케이블 공간 사이의 재료 간섭은 없다.
- 실제 CAD 기반 조립 미리보기와 표정 이미지의 외관을 확인했다. STL은 shell과 base 각1개이며 편집 원본은 `cad/enclosure.py`다.

## 코드 검토 보완

검토에서 발견한 전체 API 시간 제한과 비동기 녹음 표시 문제를 모두 수정했다. API 요청은 자식 프로세스로 격리하여 제한시간 초과 시 종료·회수한다. 키는 명령행에 넣지 않고 표준입력으로 전달한다. SPI 전송은 잠금으로 직렬화하며 상태 변경 시 프레임 전송이 끝난 뒤 반환한다.

검증은 Windows 개발 환경에서 수행했다. Pi의 GPIO/ALSA 및 systemd 실제 실행, 실물 케이스 끼움과 배선, 실제 계정 모델 권한은 별도 확인이 필요하다. 별도 기구 검토 에이전트는 실행 한도 때문에 완료되지 않았고, 제작 에이전트의 검증 결과와 원본·치수·배선 일치 여부를 주 작업에서 확인했다.

## 실물 합격 기준 — 아직 수행하지 않음

| 시험 | 합격 기준 |
|---|---|
| 무전원 가조립 | PCB·유리·단자·케이블이 눌리지 않고 나사/타이/SD에 접근 가능 |
| 상판 전극 | 외부에서 보이지 않으며 조립된 케이스 접촉으로 안정적으로 감지. 비접촉 거리는 실측 기록 |
| 터치50회 | 접촉1회당 대화1회, 누른 채 부팅/처리 완료 후 반복 녹음 없음 |
| 무발화10회 | 약5초 후 취소, API 요청 없음. 주변 소음에 따른 RMS 기준 조정 |
| 녹음·재생 | 한국어 음성 전달, 충분한 음량, 클리핑·지속 잡음 없음 |
| API 연동 | 본인 키로 음성 이해·응답·TTS 성공.401/잔액 부족/잘못된 모델 시 오류 후 복귀 |
| Wi-Fi 단절/복구 | 요청 제한시간 내 실패하고 연결 복구 후 새 접촉으로 다시 작동 |
| 화면 장애 | 듣기 표시 전송 실패 시 녹음 시작하지 않음. 실제 패널 고장 검출까지 보장하지 않음 |
| 연속30분 | 저전압/스로틀링·불안정 재부팅 없음. 온도 기록, 통풍 재검토 |
| 부팅 서비스 | 전용 계정에서 SPI/GPIO/오디오 접근, 자동 시작·종료·재시작 확인 |

이 결과는 제작용 프로토타입의 소프트웨어·기하 검증이며 실물 완제품 인증이나 제조 공차 보증이 아니다.

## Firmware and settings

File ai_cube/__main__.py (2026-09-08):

"""Run: python -m ai_cube --simulate, --doctor, --display-test, or no flags."""

import argparse
import logging
import os
from pathlib import Path
import shutil
import signal
import subprocess
import time

from .config import Settings
from .core import TouchLatch, run_turn

LOG = logging.getLogger('ai_cube')


def load_env(path):
    """Load literal KEY=VALUE entries only; no shell expansion or execution."""
    path = Path(path)
    if not path.exists():
        return
    for number, line in enumerate(path.read_text(encoding='utf-8-sig').splitlines(), 1):
        line = line.strip()
        if not line or line.startswith('#'):
            continue
        if '=' not in line:
            raise ValueError('Invalid environment file line %d' % number)
        key, value = line.split('=', 1)
        os.environ.setdefault(key.strip(), value.strip().strip('\"\''))


def preview(directory):
    from PIL import Image, ImageDraw
    from .faces import STATES, render_face
    directory = Path(directory)
    directory.mkdir(parents=True, exist_ok=True)
    sheet = Image.new('RGB', (1200, 276), '#10181d')
    draw = ImageDraw.Draw(sheet)
    frames = []
    for index, state in enumerate(STATES):
        sheet.paste(render_face(state, .5), (index * 240, 0))
        draw.text((index * 240 + 85, 250), state, fill='white')
        frames.extend(render_face(state, i / 10) for i in range(20))
    sheet.save(directory / 'expressions.png')
    frames[0].save(directory / 'expressions.gif', save_all=True,
                   append_images=frames[1:], duration=100, loop=0)


def simulate(directory):
    from .audio import pcm_to_wav
    from .faces import render_face
    target = Path(directory)
    target.mkdir(parents=True, exist_ok=True)
    class Audio:
        def record(self):
            return pcm_to_wav(b'\0\0' * 320)
        def play(self, data):
            print('SIMULATED speaker output (no device opened)')
    class Provider:
        def answer(self, data):
            return '안녕, 나는 AI 큐브야.'
        def speak(self, text):
            return b'simulated'
    def state(name):
        print(name)
        render_face(name, .5).save(target / (name + '.png'))
    run_turn(Audio(), Provider(), state)
    preview(target)
    print('Offline simulation complete; no network, microphone or speaker used.')


def doctor(settings):
    print('Capture:', settings.capture_device)
    print('Playback:', settings.playback_device)
    print('API key:', 'configured' if settings.key else 'missing')
    print('SPI0.0:', Path('/dev/spidev0.0').exists())
    for program in ('arecord', 'aplay'):
        if shutil.which(program):
            subprocess.run([program, '-l'], check=False, timeout=10)
        else:
            print(program + ': missing (install alsa-utils on Pi)')
    print('Read-only inventory; this does not verify physical wiring or API access.')


def hardware_run(settings, display_test=False, sensor_test=False):
    from .display import FaceDisplay
    from .faces import STATES
    from gpiozero import DigitalInputDevice
    from .audio import AlsaAudio
    from .provider import OrcaClient
    # Validate provider settings before opening any devices, except offline tests.
    provider = None if display_test or sensor_test else OrcaClient(
        settings.key, settings.base_url, settings.model, settings.tts_model,
        settings.voice, settings.api_timeout)
    if sensor_test:
        with DigitalInputDevice(17, pull_up=False) as sensor:
            previous = None
            while True:
                active = sensor.is_active
                if active != previous:
                    print('detected' if active else 'released', flush=True)
                    previous = active
                time.sleep(.02)
    face = FaceDisplay(settings.rotation)
    try:
        if display_test:
            for state in STATES:
                face.show(state)
                time.sleep(3)
            face.check()
            return
        with DigitalInputDevice(17, pull_up=False) as sensor:
            latch = TouchLatch()
            audio = AlsaAudio(settings)
            LOG.info('Ready; remove hand from head to arm')
            while True:
                face.check()
                if latch.update(sensor.is_active, time.monotonic()):
                    try:
                        run_turn(audio, provider, face.show)
                    except Exception as exc:
                        # Class name only: exception chains may contain remote data.
                        LOG.warning('Interaction failed (%s); check device/API configuration', type(exc).__name__)
                    finally:
                        latch.reset()
                time.sleep(.02)
    finally:
        face.close()


def main():
    parser = argparse.ArgumentParser(description='AI Cube Raspberry Pi voice companion')
    modes = parser.add_mutually_exclusive_group()
    modes.add_argument('--simulate', action='store_true', help='offline simulated interaction and face previews')
    modes.add_argument('--doctor', action='store_true', help='read-only device inventory')
    modes.add_argument('--display-test', action='store_true', help='cycle real LCD states; no API or recording')
    modes.add_argument('--sensor-test', action='store_true', help='print real sensor edges; no recording')
    parser.add_argument('--env-file', default='.env')
    parser.add_argument('--output', default='artifacts/faces')
    args = parser.parse_args()
    logging.basicConfig(level=logging.INFO, format='%(levelname)s %(message)s')
    def stop(signum, frame):
        raise KeyboardInterrupt
    signal.signal(signal.SIGTERM, stop)
    try:
        if args.simulate:
            simulate(args.output)
            return 0
        load_env(args.env_file)
        settings = Settings.from_env()
        if args.doctor:
            doctor(settings)
        else:
            hardware_run(settings, args.display_test, args.sensor_test)
    except KeyboardInterrupt:
        LOG.info('Stopped')
    except Exception as exc:
        LOG.error('Startup/device failure (%s); see docs/setup.md', type(exc).__name__)
        return 1
    return 0


if __name__ == '__main__':
    raise SystemExit(main())

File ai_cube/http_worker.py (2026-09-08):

"""Private cancellable HTTP process. Binary response on stdout, safe errors on stderr."""
import json
import sys
import urllib.request
from .provider import OrcaClient, NoRedirect, ProviderError


def main():
    try:
        item = json.loads(sys.stdin.buffer.read())
        # Caller has validated the configured HTTPS base. An isolated opener also
        # makes the transport usable with loopback fixtures in integration tests.
        client = OrcaClient(item['key'], timeout=item['timeout'],
                            opener=urllib.request.build_opener(NoRedirect()).open)
        client.base = item['url']
        data = client._post('', item['payload'], item['limit'])
        sys.stdout.buffer.write(data)
        return 0
    except ProviderError as exc:
        sys.stderr.write(str(exc))
    except Exception:
        sys.stderr.write('OrcaRouter request worker failed')
    return 1


if __name__ == '__main__':
    raise SystemExit(main())
